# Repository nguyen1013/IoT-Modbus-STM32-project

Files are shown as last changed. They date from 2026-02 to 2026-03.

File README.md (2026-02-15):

# IoT-Modbus-STM32-project (this project is a work in progress)

## 1. Introduction
This project showcases a compact but realistic home‑automation system built with STM32 microcontrollers, Modbus RTU over RS‑485, and cloud integration via an IoT gateway. Each STM32 node gathers sensor data—temperature, humidity, light, CO₂, and AC voltage—and sends it to a PC gateway for processing and visualisation. The setup highlights practical embedded engineering: real‑time operation, safe hardware design, reliable communication, and a scalable architecture suitable for smart‑home or educational use.

<p align="center">
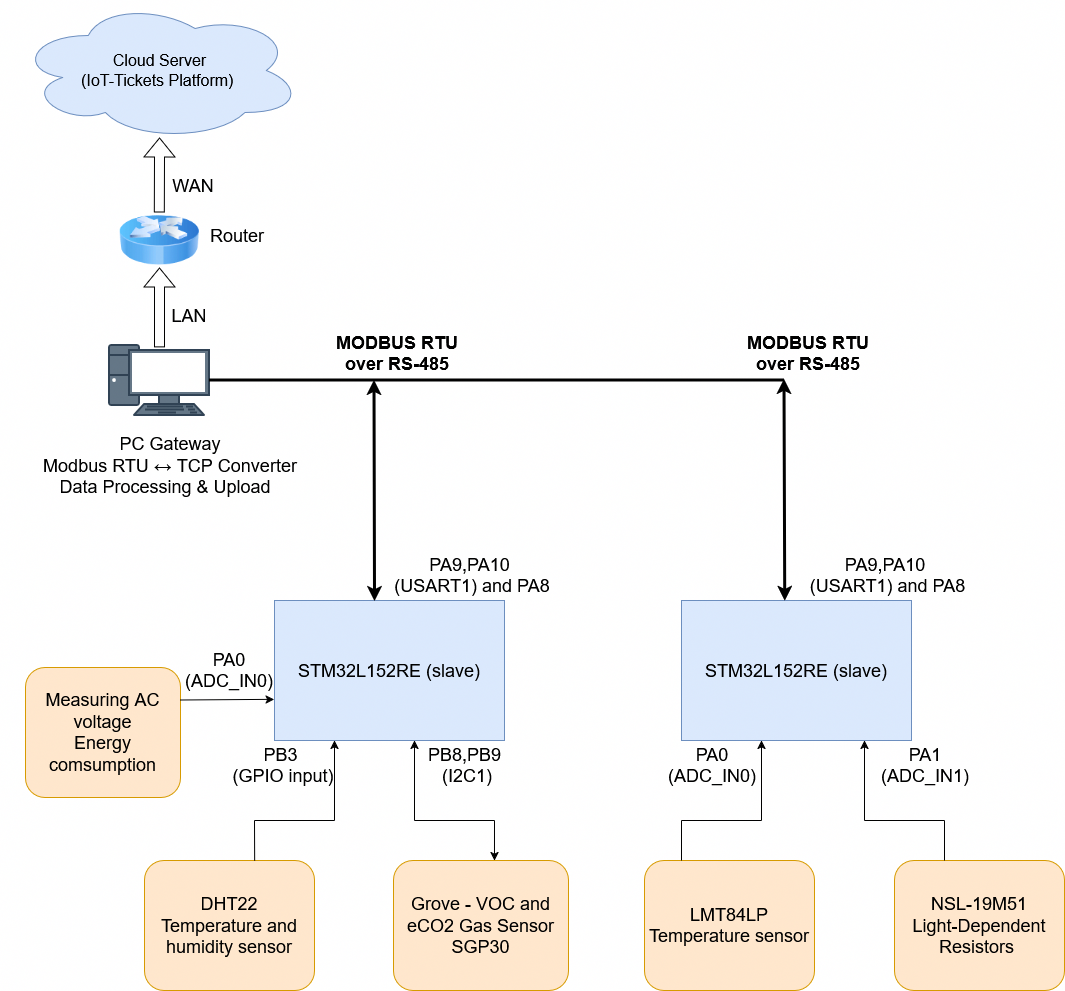
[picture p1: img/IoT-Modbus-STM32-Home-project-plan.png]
  <br>
  <b>The General Project Architecture</b>
</p>

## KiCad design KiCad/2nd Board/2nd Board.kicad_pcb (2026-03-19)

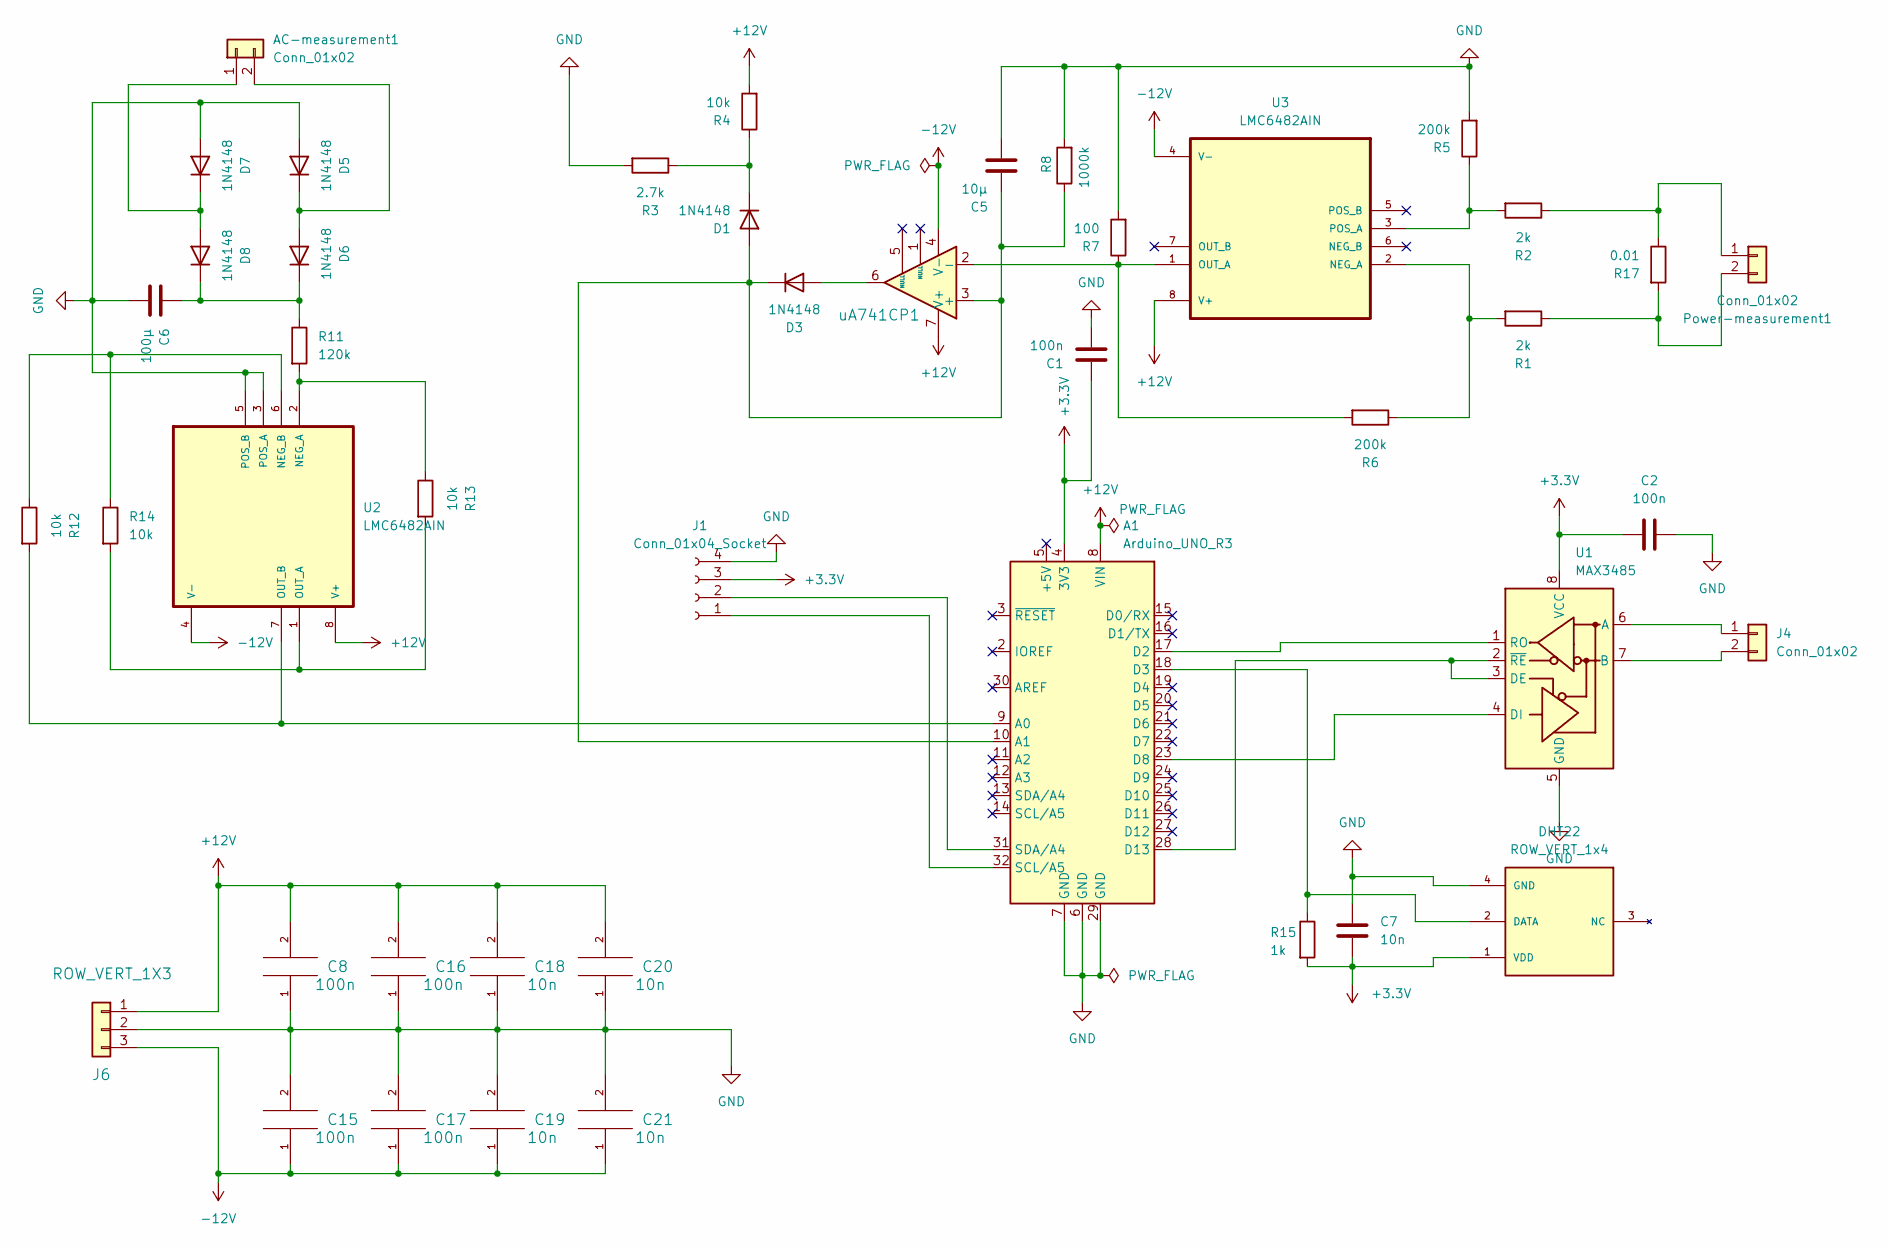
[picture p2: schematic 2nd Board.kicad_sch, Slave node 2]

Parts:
A1: Arduino_UNO_R3
AC-measurement1: Conn_01x02; ROW_VERT_1x2
C1, C2: 100n; C_0805_2012Metric
C5: 10μ; C5_0
C6: 100μ; C5_0
C7: 10n; C5_0
C8, C15, C16, C17: 100n; C5_0; Tolerance +-10%
C18, C19, C20, C21: 10n; C5_0; Tolerance +-10%
D1, D3, D5, D6, D7, D8: 1N4148; D_DO-35_SOD27_P7.62mm_Horizontal
DHT22: ROW_VERT_1x4
J1: Conn_01x04_Socket; SOCKET_1x4
J4: Conn_01x02; ROW_VERT_1x2
J6: ROW_VERT_1X3; ROW_VERT_1x3
Power-measurement1: Conn_01x02; ROW_VERT_1x2
R1, R2: 2k; R3_5W
R3: 2.7k; R3_5W
R4, R12, R13, R14: 10k; R3_5W
R5, R6: 200k; R3_5W
R7: 100; R3_5W
R8: 1000k; R3_5W
R11: 120k; R3_5W
R15: 1k; R3_5W
R17: 0.01; R3_5W
U1: MAX3485; DIP-8_W7.62mm
U2, U3: LMC6482AIN; DIP794W45P254L959H508Q8
uA741CP1: uA741CP_DIL8; DIL8

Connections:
+3.3V: A1.4 (3V3), C1.1, C2.1, C7.2, DHT22.1 (VDD), J1.3, R15.2, U1.8 (VCC)
+12V: A1.8 (VIN), C8.2, C16.2, C18.2, C20.2, J6.1, R4.2, U2.8 (V+), U3.8 (V+), uA741CP1.7 (V+)
-12V: C15.1, C17.1, C19.1, C21.1, J6.3, U2.4 (V-), U3.4 (V-), uA741CP1.4 (V-)
GND: A1.6 (GND), A1.7 (GND), A1.29 (GND), C1.2, C2.2, C5.2, C6.2, C7.1, C8.1, C15.2, C16.1, C17.2, C18.1, C19.2, C20.1, C21.2, D5.2 (A), D7.2 (A), DHT22.4 (GND), J1.4, J6.2, R3.2, R5.2, R7.2, R8.2, U1.5 (GND), U2.3 (POS_A), U2.5 (POS_B)
unnamed: A1.9 (A0), R12.2, U2.7 (OUT_B)
unnamed: A1.10 (A1), C5.1, D1.2 (A), D3.1 (K), R8.1, uA741CP1.3 (+)
unnamed: A1.17 (D2), U1.1 (RO)
unnamed: A1.18 (D3), DHT22.2 (DATA), R15.1
unnamed: A1.23 (D8), U1.4 (DI)
unnamed: A1.28 (D13), U1.2 (~RE), U1.3 (DE)
unnamed: AC-measurement1.1, D7.1 (K), D8.2 (A)
unnamed: AC-measurement1.2, D5.1 (K), D6.2 (A)
unnamed: D1.1 (K), R3.1, R4.1
unnamed: D3.2 (A), uA741CP1.6
unnamed: C6.1, D6.1 (K), D8.1 (K), R11.1
unnamed: A1.32 (SCL/A5), J1.1
unnamed: A1.31 (SDA/A4), J1.2
unnamed: J4.1, U1.6 (A)
unnamed: J4.2, U1.7 (B)
unnamed: Power-measurement1.1, R2.1, R17.1
unnamed: Power-measurement1.2, R1.1, R17.2
unnamed: R11.2, R13.1, U2.2 (NEG_A)
unnamed: R12.1, R14.1, U2.6 (NEG_B)
unnamed: R13.2, R14.2, U2.1 (OUT_A)
unnamed: R1.2, R6.1, U3.2 (NEG_A)
unnamed: R6.2, R7.1, U3.1 (OUT_A), uA741CP1.2 (-)
unnamed: R2.2, R5.1, U3.3 (POS_A)

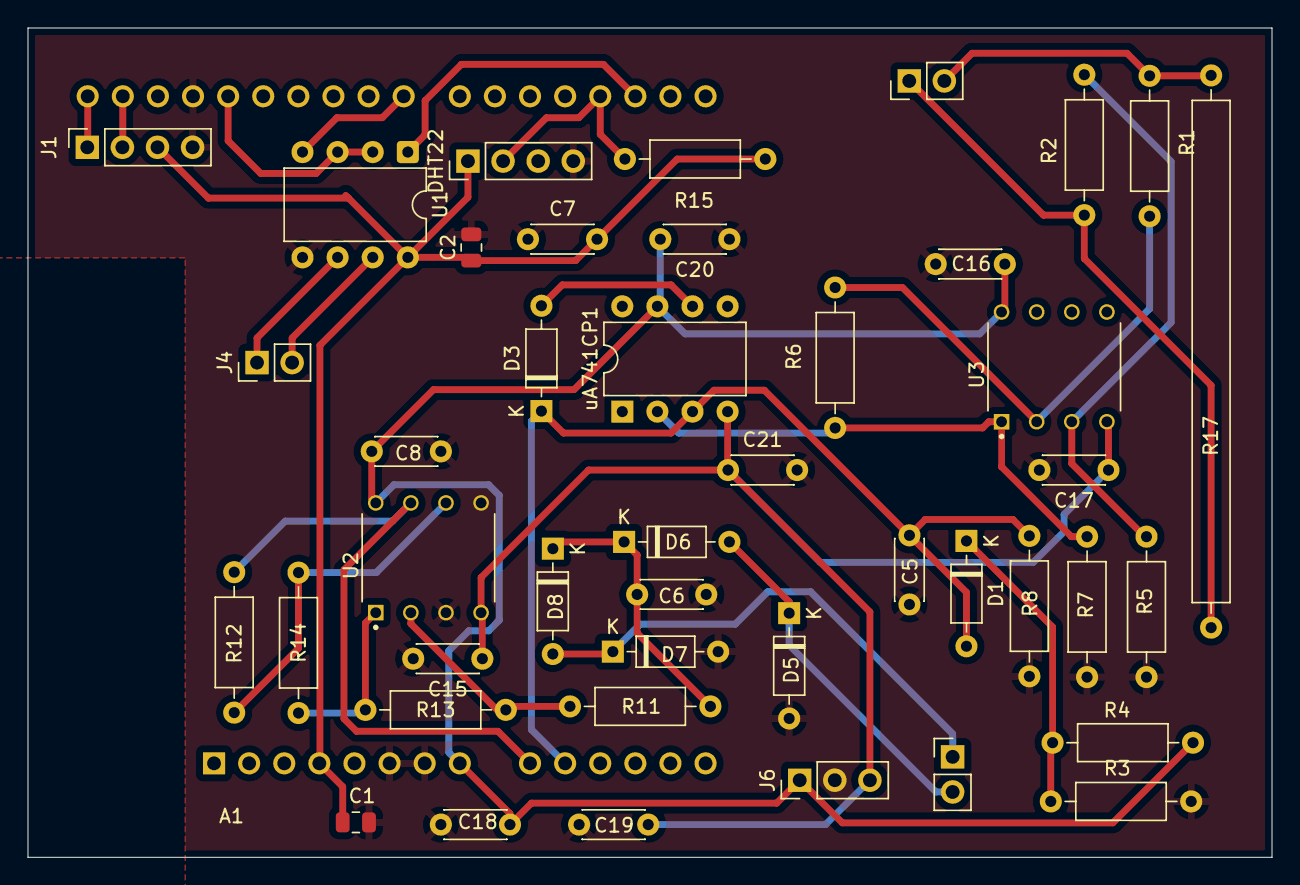
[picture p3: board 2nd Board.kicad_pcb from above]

Board: 2 copper layers, 90.0 x 60.0 mm, 44 parts (1 on the bottom side), 27 nets.

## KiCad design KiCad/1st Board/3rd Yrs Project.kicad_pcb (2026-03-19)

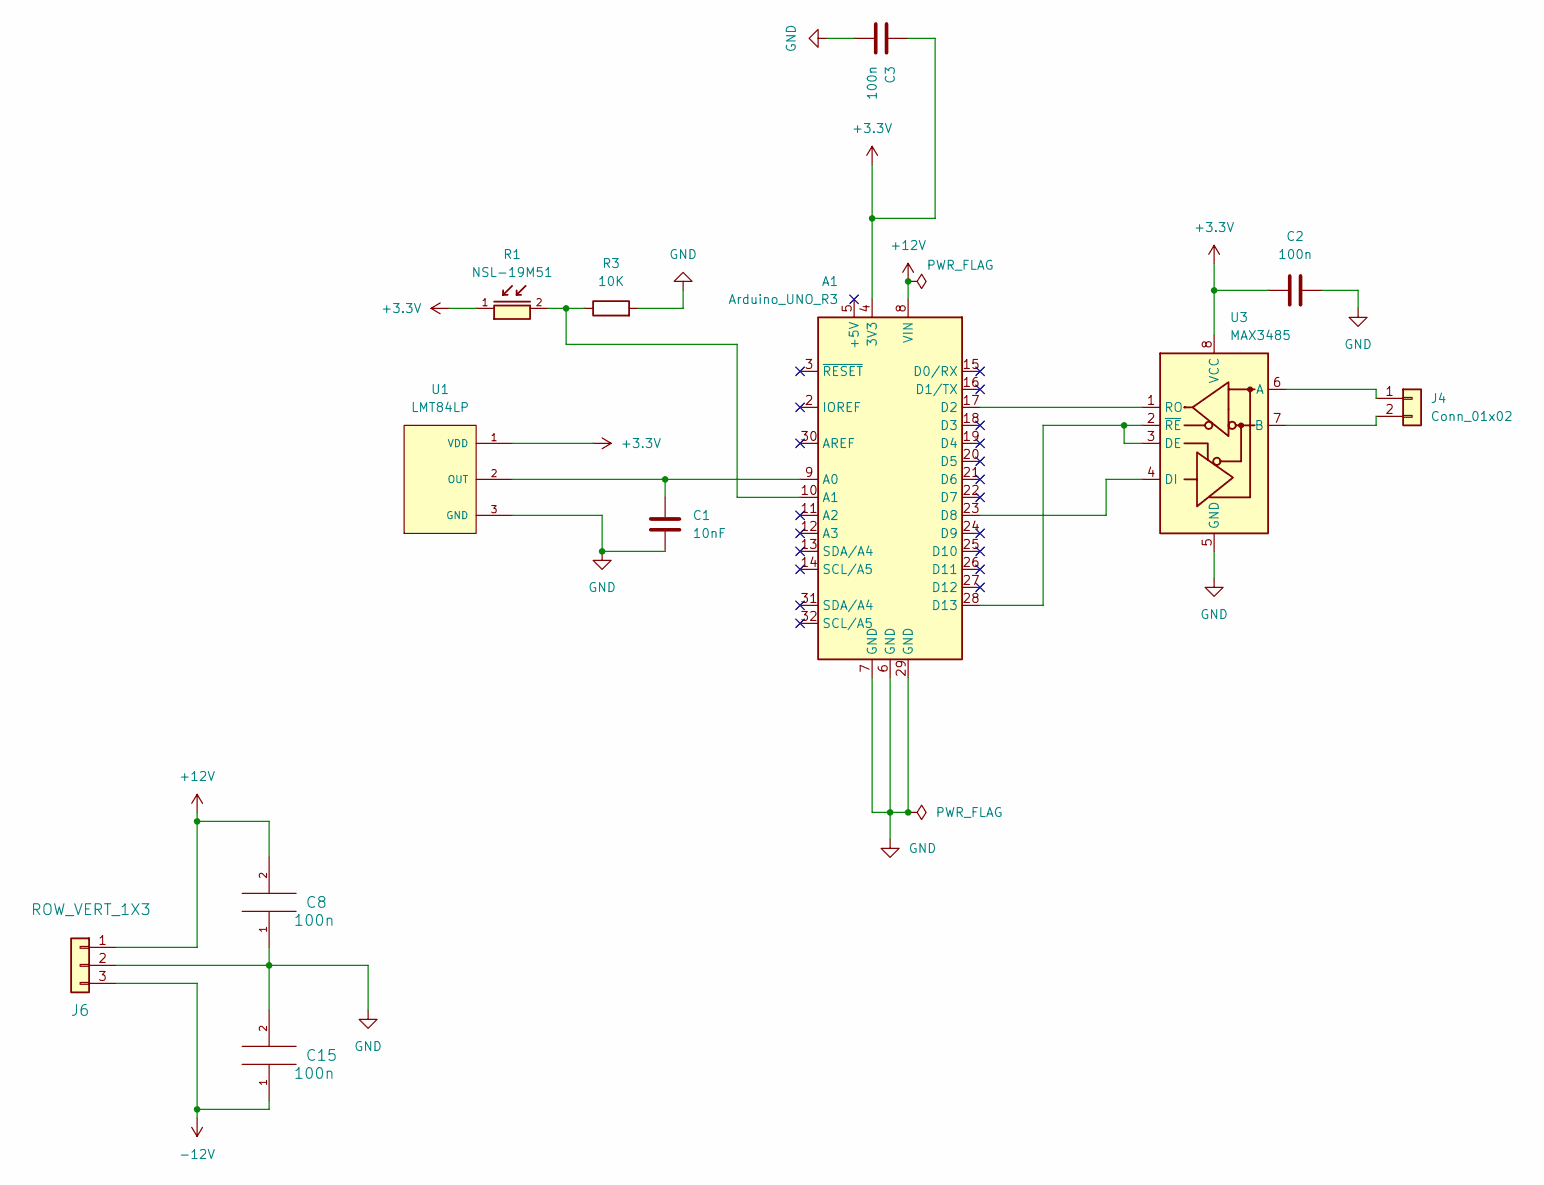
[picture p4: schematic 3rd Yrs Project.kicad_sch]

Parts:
A1: Arduino_UNO_R3
C1: 10nF; C5_0
C2, C3: 100n; C5_0
C8, C15: 100n; C5_0; Tolerance +-10%
J4: Conn_01x02; ROW_VERT_1x2
J6: ROW_VERT_1X3; ROW_VERT_1x3
R1: NSL-19M51; ROW_VERT_1x2
R3: 10K; R3_5W
U1: LMT84LP; ROW_VERT_1x3; PARTREV 4215214/B
U3: MAX3485; DIP762W47P254L991H457Q8

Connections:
+3.3V: A1.4 (3V3), C2.1, C3.1, R1.1, U1.1 (VDD), U3.8 (VCC)
+12V: A1.8 (VIN), C8.2, J6.1
-12V: C15.1, J6.3
GND: A1.6 (GND), A1.7 (GND), A1.29 (GND), C1.1, C2.2, C3.2, C8.1, C15.2, J6.2, R3.2, U1.3 (GND), U3.5 (GND)
unnamed: A1.9 (A0), C1.2, U1.2 (OUT)
unnamed: A1.10 (A1), R1.2, R3.1
unnamed: A1.17 (D2), U3.1 (RO)
unnamed: A1.23 (D8), U3.4 (DI)
unnamed: A1.28 (D13), U3.2 (~RE), U3.3 (DE)
unnamed: J4.1, U3.6 (A)
unnamed: J4.2, U3.7 (B)

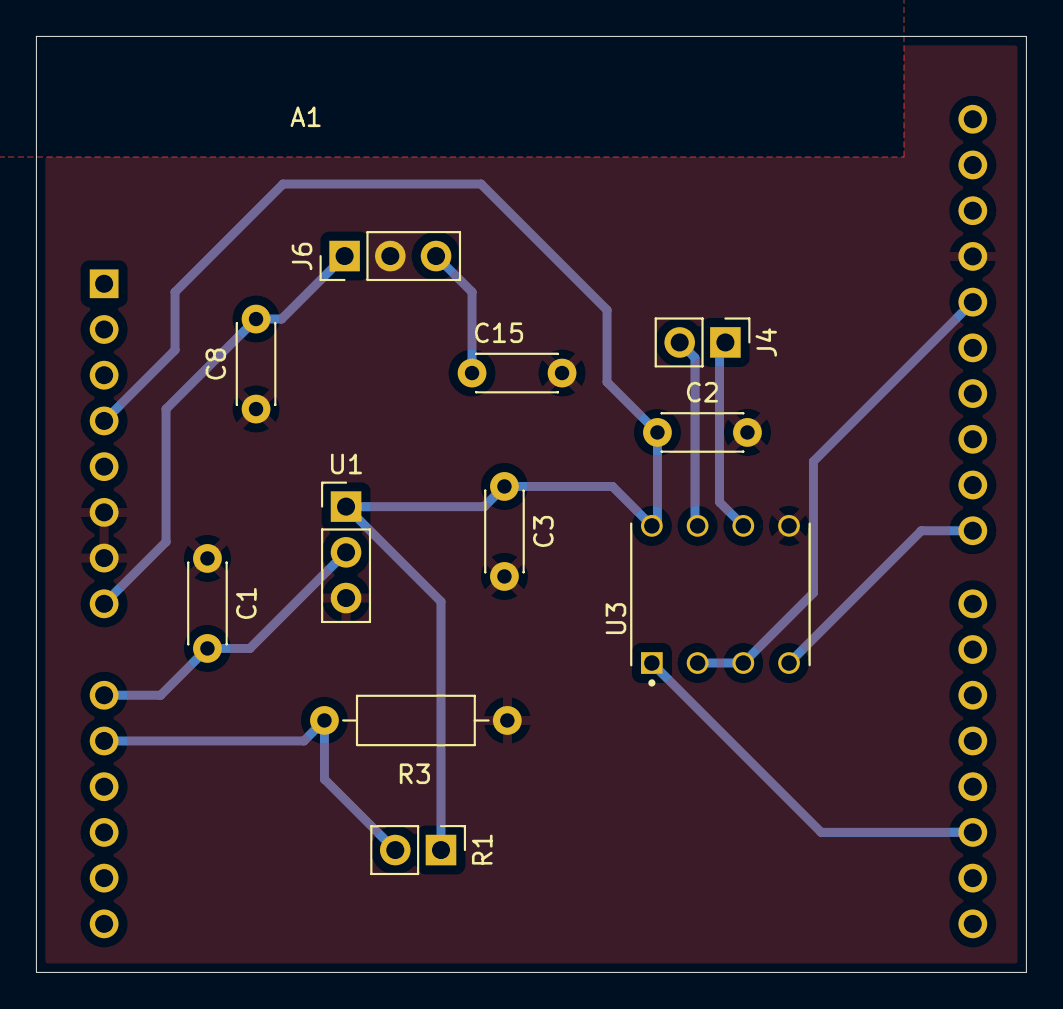
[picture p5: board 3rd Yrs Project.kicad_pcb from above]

Board: 2 copper layers, 55.0 x 52.0 mm, 12 parts (0 on the bottom side), 11 nets.

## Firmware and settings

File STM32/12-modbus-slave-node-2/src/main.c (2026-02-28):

#include "stm32l1xx.h"
#include "nucleo152start.h"
#include <stdio.h>
#include <stdlib.h>

#include "usart2.h"
#include "usart1.h"
#include "led_PA5.h"
#include "adc.h"
#include "i2c1.h"
#include "modbus_slave.h"
#include "./sensors/one-wire-dht22.h"
#include "./sensors/sgp30.h"
#include "./sensors/humidity.h"
#include "read_dht22_sgp30.h"
#include "read_adc_sensor.h"

int32_t read_sensor(uint8_t input_address);

/************************************************************************/
/* Flags are volatile, since the flag value can change during interrupt */
/* handler. Therefore compiler can handle it correctly.                 */
/************************************************************************/
volatile char mFlag = 0;
volatile uint8_t neFlag = 0;
volatile uint8_t frameFlag = 0;

/* Modbus request buffer:
 slave + func + addrH + addrL + qtyH + qtyL + crcL + crcH = 8 bytes */
volatile uint8_t request_frame[8];
volatile uint8_t rx_index = 0;
volatile uint8_t frame_ready = 0;

char buf[64];

/* ================= MAIN ================= */

int main(void) {
	__disable_irq();		//global disable IRQs, M3_Generic_User_Guide p135.

	/* Configure the system clock to 32 MHz and update SystemCoreClock */
	SetSysClock();
	SystemCoreClockUpdate();

	USART1_Init();   // Modbus RTU
	USART2_Init();   // Debug
	ADC_init();
	LED_Init();
	I2C1_init();
	DHT22_init();

	sgp30_warmup();

	modbus_slave_init();

	USART1->CR1 |= USART_CR1_RXNEIE;   // RX interrupt enable
	NVIC_EnableIRQ(USART1_IRQn);

	__enable_irq();

	while (1) {
		if (frameFlag) {
			USART2_WriteString("Framing Error Detected");
			frameFlag = 0;
		}

		if (neFlag) {
			USART2_WriteString("Noise Error Detected");
			neFlag = 0;
		}

		/* -------- Complete Modbus frame received -------- */
		if (frame_ready) {
			write_debug_frame(request_frame, 8);
			uint16_t crc = CRC16((char*) request_frame, 6);

			/* CRC validation */
			if (request_frame[6] == (crc & 0xFF)
					&& request_frame[7] == ((crc >> 8) & 0xFF)) {
				uint8_t slave_addr = request_frame[0];

				if (slave_addr >= 0x03 && slave_addr <= 0x06) {
					/* Function code 0x04 (Read Input Registers)
					 Start address 0x0001
					 Quantity 0x0002 */
					if (request_frame[1] == 0x04 && request_frame[2] == 0x00
							&& request_frame[3] == 0x01
							&& request_frame[4] == 0x00
							&& request_frame[5] == 0x02) {
						int32_t sensor_value = read_sensor(slave_addr);

						/* Valid response only if sensor OK */
						if (sensor_value != -9999) {
							respond_frame(slave_addr, sensor_value);
						}
					}
				}
			}

			frame_ready = 0;
		}
	}
}

void USART1_IRQHandler(void) {
	/* Framing error */
	if (USART1->SR & USART_SR_FE) {
		frameFlag = 1;
	}

	/* Noise error */
	if (USART1->SR & USART_SR_NE) {
		neFlag = 1;
	}

	/* RX not empty */
	if (USART1->SR & USART_SR_RXNE) {
		uint8_t byte = USART1->DR;

		if (!frame_ready)   // ignore bytes while previous frame is pending
		{
			request_frame[rx_index++] = byte;

			if (rx_index >= 8) {
				frame_ready = 1;
				rx_index = 0;
			}
		}
	}
}

/**
 * Read sensor value based on input address.
 * input_address: 0x03 → temperature-humidity (dht22)
 *                0x04 → TVOC-eCO2 (sgp30)
 *                0x05 → AC voltage (mV)
 *                0x06 → power consumption (mW)
 * Returns sensor value as int32_t,
 *         -9999 if unknown address,
 *         -9990 if sensor error
 */
int32_t read_sensor(uint8_t input_address) {
	switch (input_address) {

	case 0x03:
		read_dht22_safe();
		update_absolute_humidity();
		print_environment(); // debug

		if (g_temperature_x100 == -9990 || g_humidity_x100 == -9990) {
			return -9990;
		}

		uint16_t temp16 = (uint16_t) g_temperature_x100;
		uint16_t hum16 = (uint16_t) g_humidity_x100;

		return ((int32_t) temp16 << 16) | hum16;

	case 0x04:
		measure_and_print_iaq();

		if (iaq.eco2_ppm == -9990 || iaq.tvoc_ppb == -9990) {
			return -9990;
		}

		uint16_t eco2 = iaq.eco2_ppm;
		uint16_t tvoc = iaq.tvoc_ppb;

		return ((int32_t) eco2 << 16) | tvoc;

	case 0x05:   // AC Voltage (mV)
	{
		int32_t voltage_mv = read_ac_voltage_mv_median();
		if (voltage_mv == -9990)
		    return -9990;
		return voltage_mv;
	}

	case 0x06:   // Power Consumption (mW)
	{
		int32_t power_mw = read_power_mw_median();
		return power_mw;
	}

	default:
		return -9999; // invalid address
	}
}

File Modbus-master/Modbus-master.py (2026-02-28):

import time
import serial

port = serial.Serial('COM13',
                     baudrate=9600,
                     timeout=1,
                     bytesize=serial.EIGHTBITS,
                     parity=serial.PARITY_NONE,
                     stopbits=serial.STOPBITS_ONE)

def modbus_crc(data: bytes) -> int:
    crc = 0xFFFF
    for b in data:
        crc ^= b
        for _ in range(8):
            if crc & 1:
                crc >>= 1
                crc ^= 0xA001
            else:
                crc >>= 1
    return crc

def modbus_request(slave_addr: int, register_addr: int) -> int:
    print()
    frame = bytearray([
        slave_addr,
        0x04,
        (register_addr >> 8) & 0xFF,
        register_addr & 0xFF,
        0x00,
        0x02
    ])
    crc = modbus_crc(frame)
    frame.append(crc & 0xFF)        # CRC low
    frame.append((crc >> 8) & 0xFF) # CRC high

    print("{}: request: {}".format(time.strftime('%Y%m%d:%H%M%S'), frame))

    for attempt in range(1, 4):
        try:
            if not port.is_open:
                port.open()

            port.reset_input_buffer()
            port.reset_output_buffer()

            port.write(frame)
            # small pause to let slave respond; tune if needed
            time.sleep(0.05)

            resp = port.read(9)  # expected length for 2 registers
            if len(resp) != 9:
                raise IOError(f"Short/empty response (len={len(resp)})")
            else:
                print("{}: respond: {}".format(time.strftime('%Y%m%d:%H%M%S'), resp))

            # CRC check
            resp_crc = resp[-2] | (resp[-1] << 8)
            if modbus_crc(resp[:-2]) != resp_crc:
                raise IOError("CRC mismatch")

            # parse 32-bit big-endian from bytes 3..6
            value = (resp[3] << 24) | (resp[4] << 16) | (resp[5] << 8) | resp[6]
            if value & 0x80000000:
                value -= 0x100000000
            return value

        except Exception as e:
            print(f"{time.strftime('%Y%m%d:%H%M%S')}: attempt {attempt} error: {e}")
            # clear buffers and small backoff before retry
            try:
                port.reset_input_buffer()
            except Exception:
                pass
            time.sleep(0.2 * attempt)
    return -9999



devices = range(0x01, 0x08)

while True:
    # # -------- Read temperature from slave 0x01 --------
    # temp_x100 = modbus_request(0x01, 0x01)

    # if temp_x100 == -9990:
    #     print("Temperature Sensor ERROR")
    # elif -5000 <= temp_x100 <= 15000:
    #     print(temp_x100 / 100, "Celsius")
    # else:
    #     print("Temperature Invalid Response:", temp_x100)

    # time.sleep(2)



    # # -------- Read luminance from slave 0x02 --------
    # lux = modbus_request(0x02, 0x01)

    # if lux == -9990:
    #     print("Luminance Sensor ERROR")
    # elif lux >= 0:
    #     print(lux, "Lux")
    # else:
    #     print("Luminance Invalid Response:", lux)

    # time.sleep(2)



    # # read temperaturex100, humidityx100 from DHT22 (each value using 2 databytes)
    # # Slave packs: ((uint16_t)temp_x100 << 16) | (uint16_t)hum_x100
    # # -------- Read temperature & humidity from DHT22 (slave 0x03) --------
    raw_dht = modbus_request(0x03, 0x01)

    if raw_dht == -9990:
        print(f"{time.strftime('%Y%m%d:%H%M%S')}: DHT22 Sensor ERROR (-9990)")
    elif raw_dht == -9999:
        print(f"{time.strftime('%Y%m%d:%H%M%S')}: DHT22 read failed (-9999)")
    else:
        temp16 = (raw_dht >> 16) & 0xFFFF
        hum16  = raw_dht & 0xFFFF

        # Sign-extend temperature if negative
        if temp16 & 0x8000:
            temp16 -= 0x10000

        temperature_c = temp16 / 100.0
        humidity_pct  = hum16 / 100.0

        print(f"{time.strftime('%Y%m%d:%H%M%S')}: DHT22 Temperature = {temperature_c:.2f} °C, Humidity = {humidity_pct:.2f} %RH")

    time.sleep(2)

    # -------- Read eCO2 & TVOC from SGP30 (slave 0x04) --------
    # read eCO2, TVOC from Grove SGP30 (each value using 2 databytes)
    # Slave packs: ((uint16_t)eco2_ppm << 16) | (uint16_t)tvoc_ppb
    raw_sgp = modbus_request(0x04, 0x01)

    if raw_sgp == -9990:
        print(f"{time.strftime('%Y%m%d:%H%M%S')}: SGP30 Sensor ERROR (-9990)")
    elif raw_sgp == -9999:
        print(f"{time.strftime('%Y%m%d:%H%M%S')}: SGP30 read failed (-9999)")
    else:
        eco2 = (raw_sgp >> 16) & 0xFFFF
        tvoc = raw_sgp & 0xFFFF
        print(f"{time.strftime('%Y%m%d:%H%M%S')}: SGP30 eCO2 = {eco2} ppm, TVOC = {tvoc} ppb")

    time.sleep(2)


    # -------- Read AC Voltage (slave 0x05) --------
    voltage_mv = modbus_request(0x05, 0x01)

    if voltage_mv == -9990:
        print(f"{time.strftime('%Y%m%d:%H%M%S')}: AC Voltage Sensor ERROR")
    elif 0 <= voltage_mv <= 24000:
        voltage_v = voltage_mv / 1000.0
        print(f"{time.strftime('%Y%m%d:%H%M%S')}: AC Voltage = {voltage_v:.2f} V")
    else:
        print("AC Voltage Invalid Response:", voltage_mv)

    time.sleep(2)


    # -------- Read Power Consumption (slave 0x06) --------
    power_mw = modbus_request(0x06, 0x01)

    if power_mw == -9990:
        print(f"{time.strftime('%Y%m%d:%H%M%S')}: Power Sensor ERROR")
    elif 0 <= power_mw <= 24000:
        power_w = power_mw / 1000.0
        print(f"{time.strftime('%Y%m%d:%H%M%S')}: Power = {power_w:.2f} W")
    else:
        print("Power Invalid Response:", power_mw)

    time.sleep(2)

    

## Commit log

2026-01-16 driver for lmt84p and nsl-19-m51
2026-01-25 remove basic drivers
2026-01-25 update new driver lmt84lp
2026-01-25 update new driver nsl-19m51
2026-01-25 driver dht-22
2026-01-25 driver grove sgp30
2026-01-26 Kicad Project
2026-01-27 2bd PCB
    [2nd Board.kicad_pcb, 2nd Board.kicad_sch]
2026-01-27 1st PCB
    [3rd Yrs Project.kicad_pcb, 3rd Yrs Project.kicad_sch, DHT22.step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]
2026-01-31 combine sensor lmt84lp and nsl19m51 and tested with modbus
2026-01-31 revies response frame length to 9
2026-02-01 refactor lmt84lp driver
2026-02-01 refactor nsl-19m51 sensor
2026-02-04 1st Board Updated w/o OPAMP
2026-02-15 update dht22 and grove sgp30, handling failed reading slave
    [Modbus-master.py]
2026-02-28 new driver for slave node 2 (dht22, sgp30, measuring ac voltage and power consumption)
2026-02-28 update new driver for modbus slave node 1 (lmt84p, nsl19m51)
2026-02-28 LT Spice for AC and power consumption measurement
2026-02-28 update modbus master including ac measurement and power consumption
2026-03-02 1st Board UPDATED!
2026-03-02 2nd Board UPDATED!
2026-03-03 2nd Board Updated
2026-03-09 Fixed The Arduino Footprint
    The Footprint weren't accurate to be place on STM32 so I fixed it.
2026-03-09 Fixed The Arduino Footprint and Redesign PCB
2026-03-09 Redesigned The Whole PCB
2026-03-09 Redesign Whole PCB
2026-03-09 Redesigned PCB
2026-03-09 Fixed PCB
2026-03-15 PCB fixed (Put trace at the back side)
2026-03-19 PCB Final
2026-03-19 2nd Board Final
2026-03-19 1st Board Final
    [3rd Yrs Project.kicad_pcb, 3rd Yrs Project.kicad_sch]
